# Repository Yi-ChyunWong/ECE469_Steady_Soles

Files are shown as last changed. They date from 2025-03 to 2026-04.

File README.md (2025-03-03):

# ECE469Application

## Getting started

To make it easy for you to get started with GitLab, here's a list of recommended next steps.

Already a pro? Just edit this README.md and make it your own. Want to make it easy? [Use the template at the bottom](#editing-this-readme)!

## Add your files

- [ ] [Create](https://docs.gitlab.com/ee/user/project/repository/web_editor.html#create-a-file) or [upload](https://docs.gitlab.com/ee/user/project/repository/web_editor.html#upload-a-file) files
- [ ] [Add files using the command line](https://docs.gitlab.com/ee/gitlab-basics/add-file.html#add-a-file-using-the-command-line) or push an existing Git repository with the following command:

```
cd existing_repo
git remote add origin https://gitlab.oit.duke.edu/mka23/ece469application.git
git branch -M main
git push -uf origin main
```

## Integrate with your tools

- [ ] [Set up project integrations](https://gitlab.oit.duke.edu/mka23/ece469application/-/settings/integrations)

## Collaborate with your team

- [ ] [Invite team members and collaborators](https://docs.gitlab.com/ee/user/project/members/)
- [ ] [Create a new merge request](https://docs.gitlab.com/ee/user/project/merge_requests/creating_merge_requests.html)
- [ ] [Automatically close issues from merge requests](https://docs.gitlab.com/ee/user/project/issues/managing_issues.html#closing-issues-automatically)
- [ ] [Enable merge request approvals](https://docs.gitlab.com/ee/user/project/merge_requests/approvals/)
- [ ] [Set auto-merge](https://docs.gitlab.com/ee/user/project/merge_requests/merge_when_pipeline_succeeds.html)

## Test and Deploy

Use the built-in continuous integration in GitLab.

- [ ] [Get started with GitLab CI/CD](https://docs.gitlab.com/ee/ci/quick_start/index.html)
- [ ] [Analyze your code for known vulnerabilities with Static Application Security Testing (SAST)](https://docs.gitlab.com/ee/user/application_security/sast/)
- [ ] [Deploy to Kubernetes, Amazon EC2, or Amazon ECS using Auto Deploy](https://docs.gitlab.com/ee/topics/autodevops/requirements.html)
- [ ] [Use pull-based deployments for improved Kubernetes management](https://docs.gitlab.com/ee/user/clusters/agent/)
- [ ] [Set up protected environments](https://docs.gitlab.com/ee/ci/environments/protected_environments.html)

***

# Editing this README

When you're ready to make this README your own, just edit this file and use the handy template below (or feel free to structure it however you want - this is just a starting point!). Thanks to [makeareadme.com](https://www.makeareadme.com/) for this template.

## Suggestions for a good README

Every project is different, so consider which of these sections apply to yours. The sections used in the template are suggestions for most open source projects. Also keep in mind that while a README can be too long and detailed, too long is better than too short. If you think your README is too long, consider utilizing another form of documentation rather than cutting out information.

## Name
Choose a self-explaining name for your project.

## Description
Let people know what your project can do specifically. Provide context and add a link to any reference visitors might be unfamiliar with. A list of Features or a Background subsection can also be added here. If there are alternatives to your project, this is a good place to list differentiating factors.

## Badges
On some READMEs, you may see small images that convey metadata, such as whether or not all the tests are passing for the project. You can use Shields to add some to your README. Many services also have instructions for adding a badge.

## Visuals
Depending on what you are making, it can be a good idea to include screenshots or even a video (you'll frequently see GIFs rather than actual videos). Tools like ttygif can help, but check out Asciinema for a more sophisticated method.

## Installation
Within a particular ecosystem, there may be a common way of installing things, such as using Yarn, NuGet, or Homebrew. However, consider the possibility that whoever is reading your README is a novice and would like more guidance. Listing specific steps helps remove ambiguity and gets people to using your project as quickly as possible. If it only runs in a specific context like a particular programming language version or operating system or has dependencies that have to be installed manually, also add a Requirements subsection.

## Usage
Use examples liberally, and show the expected output if you can. It's helpful to have inline the smallest example of usage that you can demonstrate, while providing links to more sophisticated examples if they are too long to reasonably include in the README.

## Support
Tell people where they can go to for help. It can be any combination of an issue tracker, a chat room, an email address, etc.

## Roadmap
If you have ideas for releases in the future, it is a good idea to list them in the README.

## Contributing
State if you are open to contributions and what your requirements are for accepting them.

For people who want to make changes to your project, it's helpful to have some documentation on how to get started. Perhaps there is a script that they should run or some environment variables that they need to set. Make these steps explicit. These instructions could also be useful to your future self.

You can also document commands to lint the code or run tests. These steps help to ensure high code quality and reduce the likelihood that the changes inadvertently break something. Having instructions for running tests is especially helpful if it requires external setup, such as starting a Selenium server for testing in a browser.

## Authors and acknowledgment
Show your appreciation to those who have contributed to the project.

## License
For open source projects, say how it is licensed.

## Project status
If you have run out of energy or time for your project, put a note at the top of the README saying that development has slowed down or stopped completely. Someone may choose to fork your project or volunteer to step in as a maintainer or owner, allowing your project to keep going. You can also make an explicit request for maintainers.

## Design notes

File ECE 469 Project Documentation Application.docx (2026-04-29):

# Building the App with Swift

## Will Need

- Xcode
- Swift 5.9 or higher
- A real iOS device (Bluetooth functionality cannot be fully tested on the simulator)

## Building and Running

1. Download the project folder containing all Swift files (FallDetectionAppApp.swift, BluetoothViewModel.swift, ContentView1.swift, MainTabView.swift, etc.).
2. Open the .xcodeproj file in Xcode.
3. Connect iPhone via USB and select it as the build target.
4. Configure Signing & Capabilities:
  a. Go to the Signing & Capabilities tab.
  b. Set your personal team for code signing.
  c. Ensure Bluetooth Permissions (NSBluetoothAlwaysUsageDescription) are added to Info.plist.

Build and Run the app onto your device.

# App Use Documentation

## Setup

1. Turn on shoe device and ensure Bluetooth is enabled on your iPhone.
2. Open the Fall Detection App.
  a. The app will automatically search for and connect to the device.
  b. The connection status at the top will say "Connected to ESP32" when successful.

## Main Features (MainTabView.swift)

### Home Tab (ContentView1.swift)

- Live Pressure Heatmap (HeatmapView.swift): Displays real-time foot pressure distribution over a shoe outline.
- Fall Detection Alerts (Test_Pressure_Arduino.ino - under Hardware files; BluetoothViewModel.swift): If a dangerous lean is detected, a warning message appears over the heatmap.

### Settings Tab (SettingsView.swift)

- Calibrate Sensors (CalibrationView.swift):
  - Tap "Calibrate Sensors" to go to the Calibration Page. Tap “Start Calibration”
  - Stand still for 5 seconds while calibration completes.
- Test Motors ():
  - Tap "Test Front Motor" or "Test Back Motor" to activate motor vibration.
  - Tap "Turn off Motor" to stop vibration.
- Adjust Lean Sensitivity:
  - Use sliders to set how sensitive the app is to forward or backward leans.
  - Tap "Apply" to update thresholds.
- Battery Status:
  - Displays the current battery level of the connected device.

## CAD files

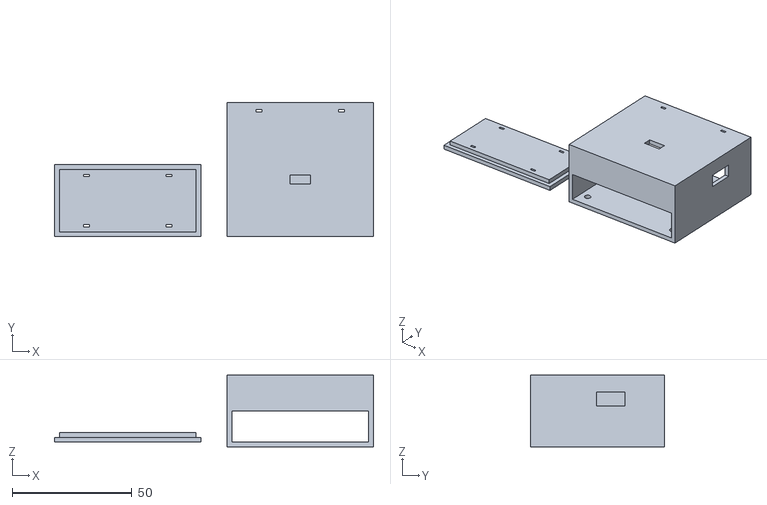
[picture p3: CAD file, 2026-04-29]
Ankle_Box/Ankle_Box_Finale v2.stl
133.0 x 56.0 x 30.0

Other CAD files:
Ankle_Box/Ankle_Box_Finale v2.gcode.3mf
Ankle_Box/Ankle_Box_Finale v2.f3d

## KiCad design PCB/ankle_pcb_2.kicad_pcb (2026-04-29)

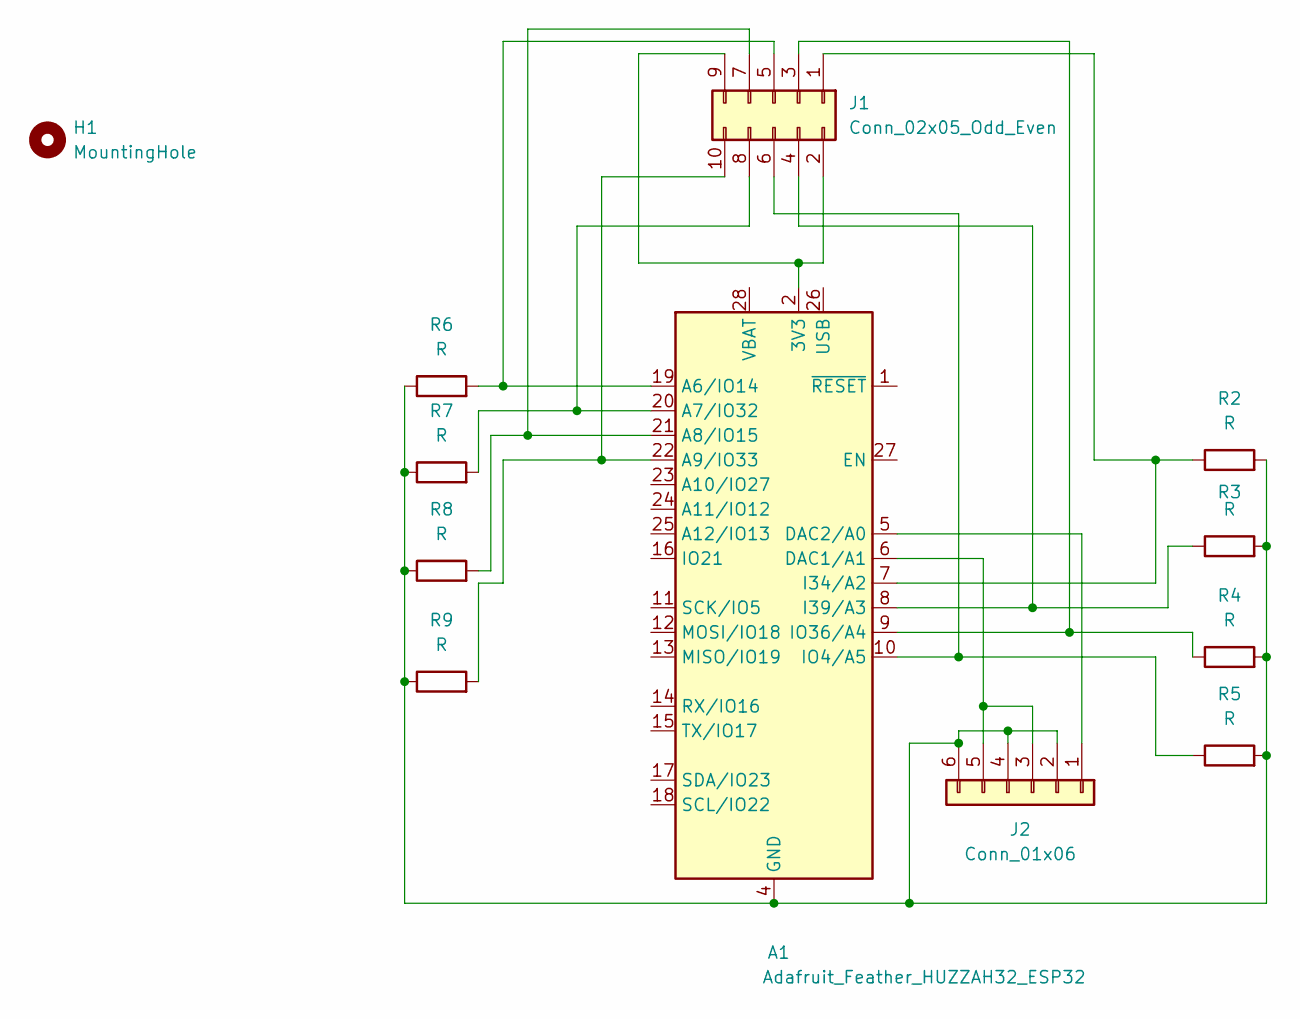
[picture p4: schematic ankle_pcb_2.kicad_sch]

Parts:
A1: Adafruit_Feather_HUZZAH32_ESP32; Adafruit_Feather
H1: MountingHole; MountingHole_2.5mm_Pad
J1: Conn_02x05_Odd_Even; PinHeader_2x05_P2.54mm_Horizontal
J2: Conn_01x06; PinHeader_1x06_P2.54mm_Horizontal
R2, R3, R4, R5, R6, R7, R8, R9: R; R_Box_L13.0mm_W4.0mm_P9.00mm

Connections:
unnamed: A1.2 (3V3), J1.2, J1.9
unnamed: A1.19 (A6/IO14), J1.5, R6.2
unnamed: A1.20 (A7/IO32), J1.8, R7.2
unnamed: A1.21 (A8/IO15), J1.7, R8.2
unnamed: A1.22 (A9/IO33), J1.10, R9.2
unnamed: A1.6 (DAC1/A1), J2.3, J2.5
unnamed: A1.5 (DAC2/A0), J2.1
unnamed: A1.4 (GND), J2.2, J2.4, J2.6, R2.2, R3.2, R4.2, R5.2, R6.1, R7.1, R8.1, R9.1
unnamed: A1.7 (I34/A2), J1.1, R2.1
unnamed: A1.8 (I39/A3), J1.4, R3.1
unnamed: A1.10 (IO4/A5), J1.6, R5.1
unnamed: A1.9 (IO36/A4), J1.3, R4.1

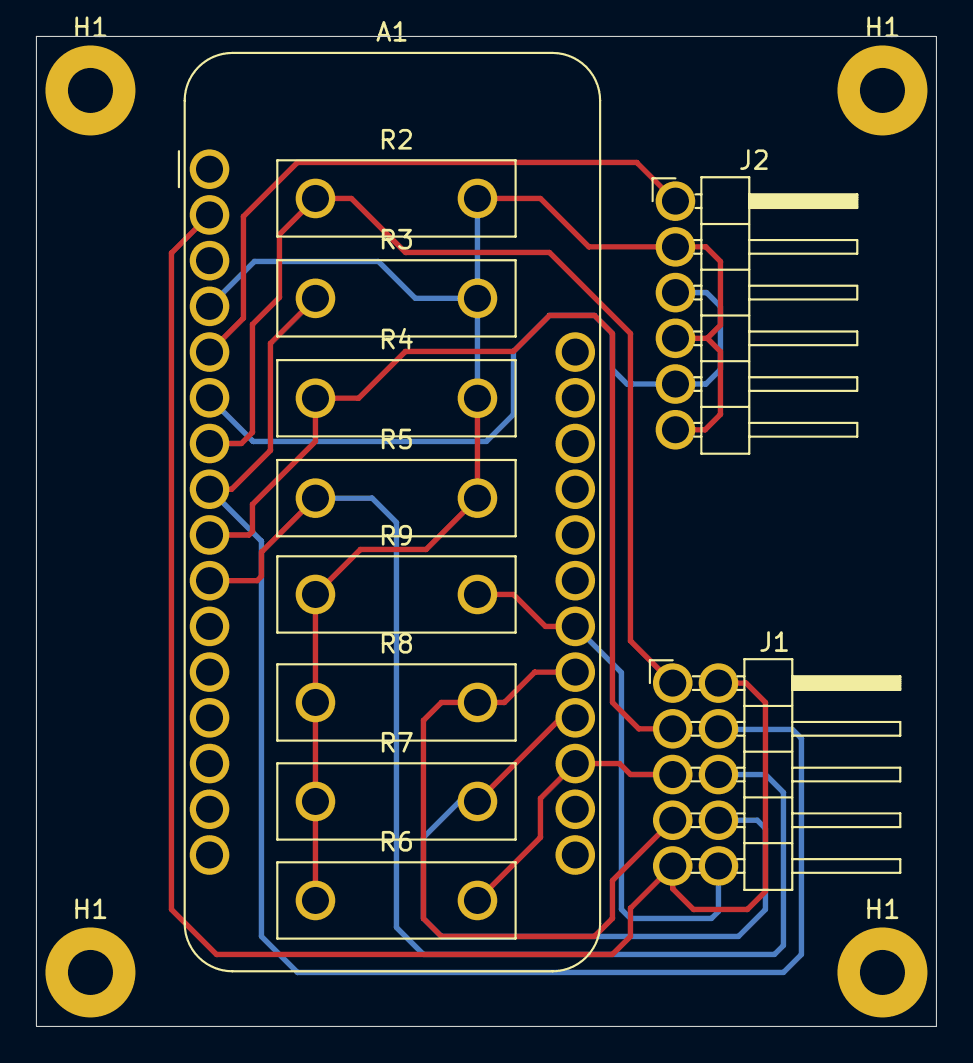
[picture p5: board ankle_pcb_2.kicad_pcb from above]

Board: 2 copper layers, 50.0 x 55.0 mm, 15 parts (0 on the bottom side), 12 nets.

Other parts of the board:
H1#2, H1#3, H1#4: MountingHole; MountingHole_2.5mm_Pad

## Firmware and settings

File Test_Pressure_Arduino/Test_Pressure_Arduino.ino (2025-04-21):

/**
*
* If you have not downloaded the driver required for ESP32 please do so first.
* Add the esp32 by Espressif Systems from Boards Manager and choose
* "Adafruit ESP32 Feather" as your board.
*
**/


#include <string.h>
#include <BLEDevice.h>
#include <BLEUtils.h>
#include <BLEServer.h>

#define VBATPIN A13

#define SERVICE_UUID        "4fafc201-1fb5-459e-8fcc-c5c9c331914b"
#define CHARACTERISTIC_UUID "beb5483e-36e1-4688-b7f5-ea07361b26a8"

int v[8];
const int motorFront = A0;
const int motorBack = A1;
bool motorTestActive = false;

BLECharacteristic *pCharacteristic;
BLEServer *pServer;
bool deviceConnected = false;

bool calibrating = false, calibrated = false;
unsigned long calibrationStartTime = 0;
int calibratedMaxValues[8] = {0};
int calibratedMinValues[8] = {4095};
int frontThreshold = 0, backThreshold = 0;

const int historySize = 5;
int pressureHistory[historySize] = {0};
int historyIndex = 0;
bool isStationary = false;


void turnMotorOn(int motor) {
  digitalWrite(motor, HIGH);
}

void turnMotorOff(int motor) {
  digitalWrite(motor, LOW);
}

void readSensors() {
  v[0] = analogRead(A2);
  v[1] = analogRead(A3);
  v[2] = analogRead(A4);
  v[3] = analogRead(A5);
  v[4] = analogRead(A6);
  v[5] = analogRead(A7);
  v[6] = analogRead(A8);
  v[7] = analogRead(A9);

  Serial.println("2\t3\t4\t5\t6\t7\t8\t9");
    for (int i = 0; i < 8; i++) {
        Serial.print(v[i]);
        Serial.print("\t");
    }
    Serial.println();
    Serial.println();
}

int calculateTotalPressure() {
  int total = 0;
  for (int i = 0; i < 8; i++) total += v[i];
  return total;
}

bool checkStationary() {
  int minP = pressureHistory[0], maxP = pressureHistory[0];
  for (int i = 1; i < historySize; i++) {
    if (pressureHistory[i] < minP) minP = pressureHistory[i];
    if (pressureHistory[i] > maxP) maxP = pressureHistory[i];
  }
  return (maxP - minP < 100);
}

void updatePressureHistory(int totalPressure) {
  pressureHistory[historyIndex] = totalPressure;
  historyIndex = (historyIndex + 1) % historySize;
  isStationary = checkStationary();
}

void sendStringBLE(std::string str) {
  pCharacteristic->setValue((uint8_t *)str.c_str(), str.length());
  pCharacteristic->notify();
}

void updateCalibration() {
  for (int i = 0; i < 8; i++) {
    if (v[i] > calibratedMaxValues[i]) calibratedMaxValues[i] = v[i];
    if (v[i] < calibratedMinValues[i]) calibratedMinValues[i] = v[i];
  }

  if (millis() - calibrationStartTime >= 5000) {
    calibrating = false;
    calibrated  = true;

    Serial.println("Calibration done:");
    for (int i = 0; i < 8; i++) {
      Serial.print("Sensor "); Serial.print(i); Serial.print(": Max = ");
      Serial.print(calibratedMaxValues[i]);
      Serial.print(", Min = "); Serial.println(calibratedMinValues[i]);
    }
  }

  // TODO: send calibrated values to app
}

class MyCallbacks : public BLECharacteristicCallbacks {
    void onWrite(BLECharacteristic *pCharacteristic) {
        std::string value = std::string(pCharacteristic->getValue().c_str());
        Serial.print("RECEIVED: ");
        Serial.println(value.c_str());

        if (value == "FRONT") {
            Serial.println("FRONT Motor ON");
            turnMotorOn(motorFront);
            turnMotorOff(motorBack);
            motorTestActive = true;
        } else if (value == "BACK") {
            Serial.println("BACK Motor ON");
            turnMotorOn(motorBack);
            turnMotorOff(motorFront);
            motorTestActive = true;
        } else if (value == "OFF") {
            Serial.println("Motor OFF");
            turnMotorOff(motorFront);
            turnMotorOff(motorBack);
            motorTestActive = false;
        } else if (value == "CALIBRATE") {
          Serial.println("Calibrating!");
          calibrating = true;
          calibrated = false;
          calibrationStartTime = millis();
          for (int i = 0; i < 8; i++) {
            calibratedMaxValues[i] = 0;
          }
        } else if (value.find("SENSITIVITY") == 0) {
          // Split by commas
          int index1 = value.find(",");
          int index2 = value.find(",", index1 + 1);
          
          if (index1 != std::string::npos && index2 != std::string::npos) {
              std::string type = value.substr(index1 + 1, index2 - index1 - 1);
              std::string valStr = value.substr(index2 + 1);                    

              float val = atoi(valStr.c_str());

              if (type == "FORWARD") {
                  frontThreshold = val;
                  Serial.printf("🔧 Forward threshold set to %d\n", frontThreshold);
              } else if (type == "BACKWARD") {
                  backThreshold = val;
                  Serial.printf("🔧 Backward threshold set to %d\n", backThreshold);
              } 
          }
          return;
        }

        else {
            Serial.println("Invalid Command");
        }

    }
};

void detectLean() {
  // if (!isStationary) {
  //   Serial.println("NOT STATIONARY");
  //   return;
  // }

  if (calculateTotalPressure() < 1000) {
    turnMotorOff(motorFront);
    turnMotorOff(motorBack);
  }

  float heelPressure = (v[0] + v[1]) / 2.0;
  float toePressure = (v[2] + v[4] + v[6]) / 3.0;
  float leanRatio = toePressure / (heelPressure + toePressure + 1e-5);

  float frontMultiplier = 1.15 + (0.2 * frontThreshold / 50.0);
  float backMultiplier = 1.15 + (0.2 * backThreshold / 50.0);

  bool toePressed = (v[2] > calibratedMaxValues[2] * frontMultiplier) ||
                    (v[4] > calibratedMaxValues[4] * frontMultiplier) ||
                    (v[6] > calibratedMaxValues[6] * frontMultiplier);
  bool heelDropped = (v[0] < calibratedMaxValues[0] * 0.4) &&
                     (v[1] < calibratedMaxValues[1] * 0.4);

  bool heelPressed = (v[0] > calibratedMaxValues[0] * backMultiplier) &&
                     (v[1] > calibratedMaxValues[1] * backMultiplier);
  bool toeDropped = (v[2] <= calibratedMaxValues[2] * 0.5) &&
                    (v[4] <= calibratedMaxValues[4] * 0.5) &&
                    (v[6] <= calibratedMaxValues[6] * 0.5);

  if ((toePressed && heelDropped)) {
    Serial.println("Leaning Forward !!!");
    turnMotorOn(motorFront);
    turnMotorOff(motorBack);

    sendStringBLE("Leaning Forward");
  } else if ((heelPressed && toeDropped)) {
    Serial.println("Leaning Backward !!!");
    turnMotorOn(motorBack);
    turnMotorOff(motorFront);

    sendStringBLE("Leaning Backward");
  } else {
    turnMotorOff(motorFront);
    turnMotorOff(motorBack);
  }
}

class ServerCallbacks : public BLEServerCallbacks {
  void onConnect(BLEServer* pServer) {
    deviceConnected = true;
    Serial.println("Device Connected");
  }

  void onDisconnect(BLEServer* pServer) {
    deviceConnected = false;
    Serial.println("Device Disconnected, Restarting Advertising...");
    BLEDevice::startAdvertising();
  }
};

void setup() {
  pinMode(motorFront, OUTPUT);
  pinMode(motorBack, OUTPUT);
  Serial.begin(921600);

  BLEDevice::init("ESP32 Motor Controller");
  pServer = BLEDevice::createServer();
  pServer->setCallbacks(new ServerCallbacks());

  BLEService *pService = pServer->createService(SERVICE_UUID);
  pCharacteristic = pService->createCharacteristic(
      CHARACTERISTIC_UUID,
      BLECharacteristic::PROPERTY_READ | BLECharacteristic::PROPERTY_WRITE | BLECharacteristic::PROPERTY_NOTIFY
  );

  pCharacteristic->setCallbacks(new MyCallbacks());
  pService->start();

  BLEAdvertising *pAdvertising = BLEDevice::getAdvertising();
  pAdvertising->addServiceUUID(SERVICE_UUID);
  pAdvertising->setScanResponse(true);
  pAdvertising->setMinPreferred(0x06);
  pAdvertising->setMinPreferred(0x12);
  BLEDevice::startAdvertising();

}

void checkBattery () {
  float measuredvbat = analogRead(VBATPIN);
  measuredvbat = (measuredvbat * 2 * 3.3) / 4096;  // voltage calculation

  char batteryMessage[32];
  snprintf(batteryMessage, sizeof(batteryMessage), "Batterylevel %.2f", measuredvbat);

  sendStringBLE(batteryMessage);  // Send formatted string over BLE
  Serial.printf("VBat: %.1f V\n", measuredvbat);  // Print to serial for debug
}

void loop() {
  readSensors();
  if (deviceConnected) checkBattery();

  std::string sensorData = "";
  for (int i = 0; i < 8; i++) {
    sensorData += std::to_string(v[i]) + ",";
  }

  if (deviceConnected) sendStringBLE(sensorData);

  if (calibrating) updateCalibration();
  
  if (calibrated && !motorTestActive) detectLean();

  delay(250);
}

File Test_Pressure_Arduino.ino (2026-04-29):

/**
*
* If you have not downloaded the driver required for ESP32 please do so first.
* Add the esp32 by Espressif Systems from Boards Manager and choose
* "Adafruit ESP32 Feather" as your board.
*
**/

const int motor_f = A0;
const int motor_b = A1;

void setup() {
  // declare the ledPin as an OUTPUT:
  pinMode(motor_f, OUTPUT);
  pinMode(motor_b, OUTPUT);
  Serial.begin(921600);
}

void loop() {
  int v_2 = analogRead(A2);
  int v_3 = analogRead(A3);
  int v_4 = analogRead(A4);
  int v_5 = analogRead(A5);
  int v_6 = analogRead(A6);
  int v_7 = analogRead(A7);
  int v_8 = analogRead(A8);
  int v_9 = analogRead(A9);
  // turn the ledPin on
  Serial.print("2");
  Serial.print("\t");
  Serial.print("3");
  Serial.print("\t");
  Serial.print("4");
  Serial.print("\t");
  Serial.print("5");
  Serial.print("\t");
  Serial.print("6");
  Serial.print("\t");
  Serial.print("7");
  Serial.print("\t");
  Serial.print("8");
  Serial.print("\t");
  Serial.print("9");
  Serial.println();

  Serial.print(v_2);
  Serial.print("\t");
  Serial.print(v_3);
  Serial.print("\t");
  Serial.print(v_4);
  Serial.print("\t");
  Serial.print(v_5);
  Serial.print("\t");
  Serial.print(v_6);
  Serial.print("\t");
  Serial.print(v_7);
  Serial.print("\t");
  Serial.print(v_8);
  Serial.print("\t");
  Serial.print(v_9);
  Serial.println();
  Serial.println();
  delay(100);

  digitalWrite(motor_f, HIGH);
  digitalWrite(motor_b, HIGH);
}

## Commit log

2025-03-06 Swift Heatmap Code
2025-03-06 Heatmap Code
2025-03-07 Added pressure sensor code to git
2025-03-26 send arduino data
2025-03-27 Heatmap showing
2025-03-27 Heatmap, Calibration, and Algorithm to Detect (still refining)
